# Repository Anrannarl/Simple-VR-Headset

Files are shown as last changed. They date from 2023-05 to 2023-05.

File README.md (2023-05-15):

# Simple-VR-Headset
A simple VR headset designed for HadesVR.  
https://github.com/HadesVR/HadesVR  
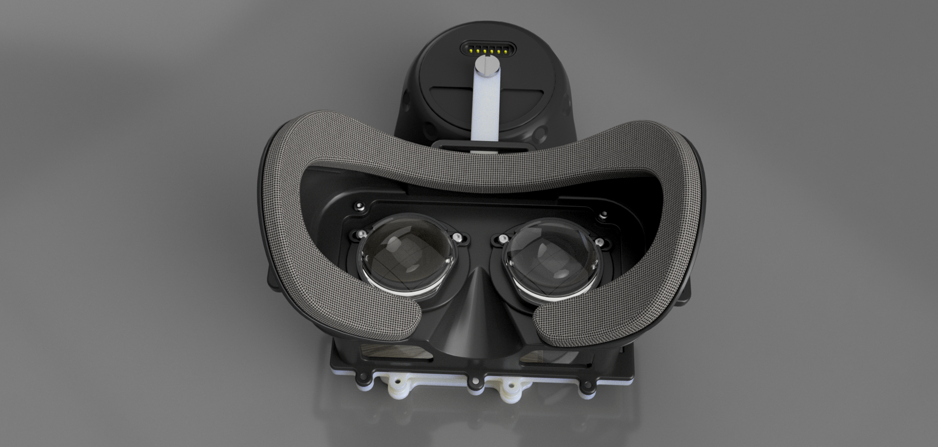
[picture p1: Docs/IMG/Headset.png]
  
  


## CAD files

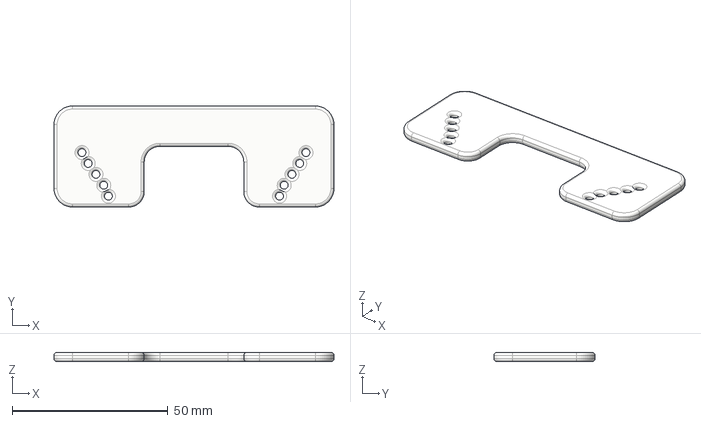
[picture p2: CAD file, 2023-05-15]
STEPs/IPD Tool.step
90.0 x 32.5 x 3.00 mm

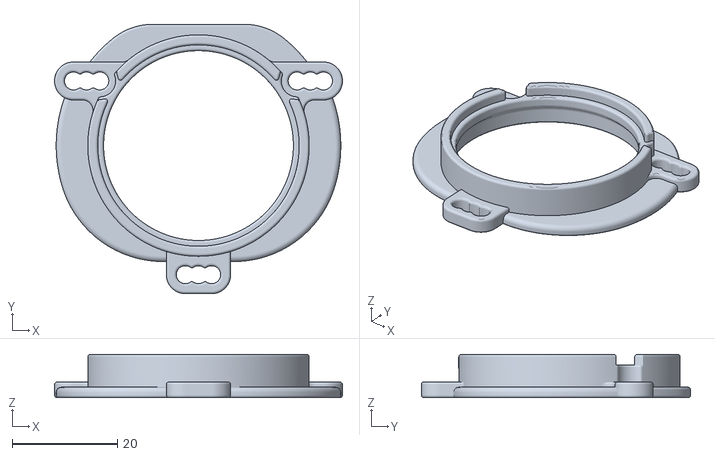
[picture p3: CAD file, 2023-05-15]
STLs/Lens Cup/GearVR White Lens Cup.stl
54.6 x 51.1 x 8.25

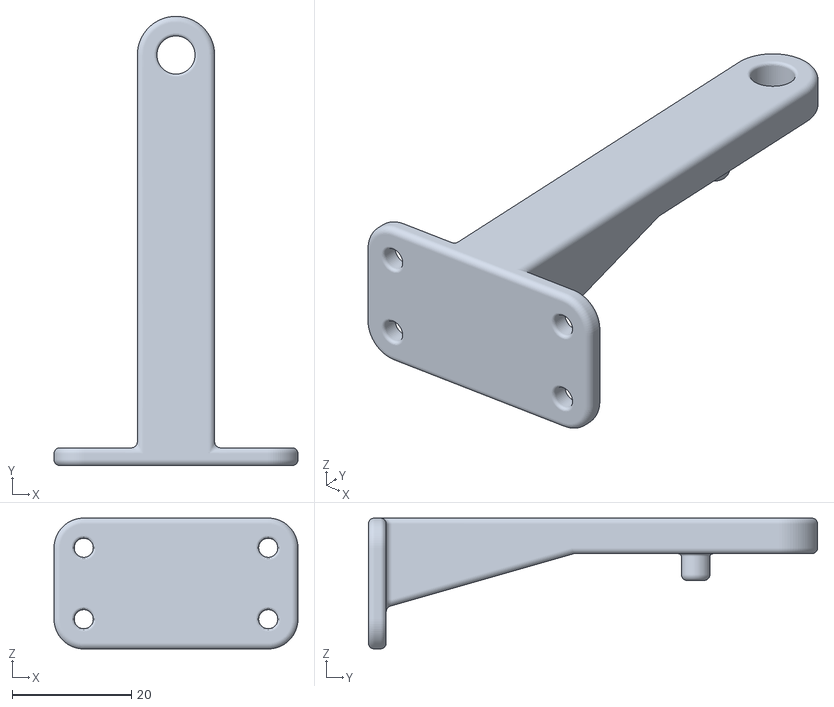
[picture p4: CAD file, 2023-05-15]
STLs/Tracker Mount.stl
41.0 x 75.5 x 22.0

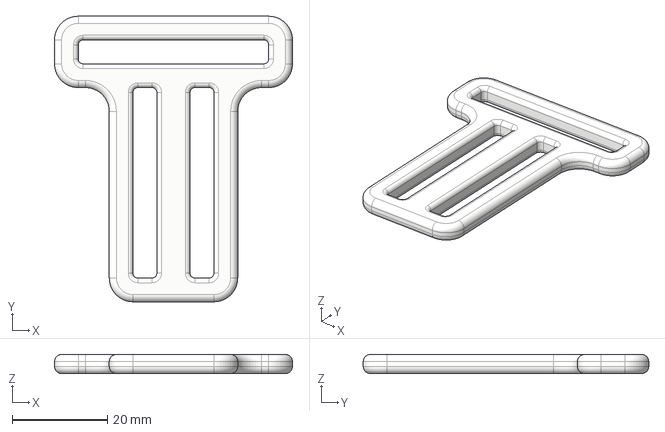
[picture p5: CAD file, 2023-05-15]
STEPs/Head Strap Hook.step
50.0 x 60.0 x 4.00 mm

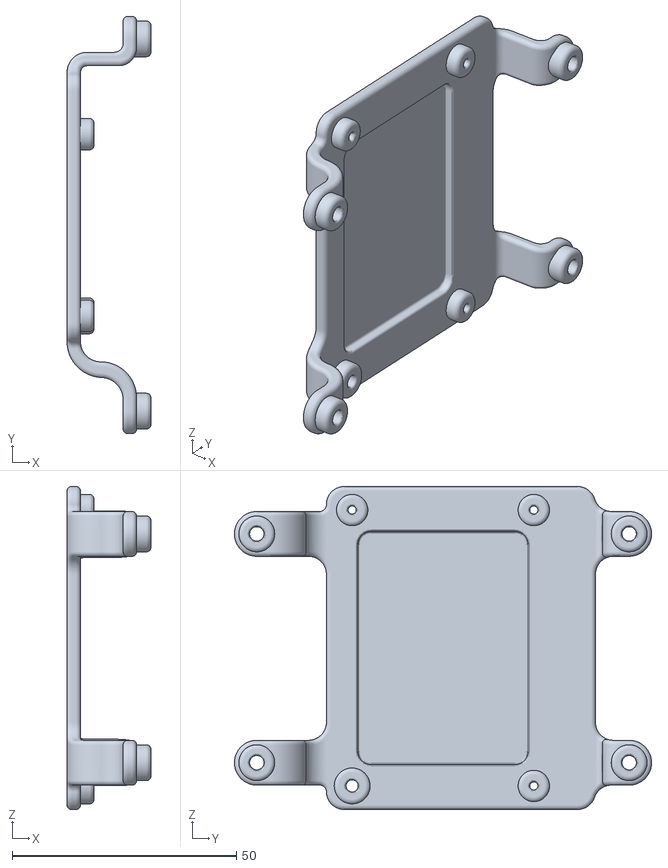
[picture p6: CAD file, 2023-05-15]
STLs/HDMI PCBA Mount.stl
18.7 x 93.0 x 72.0

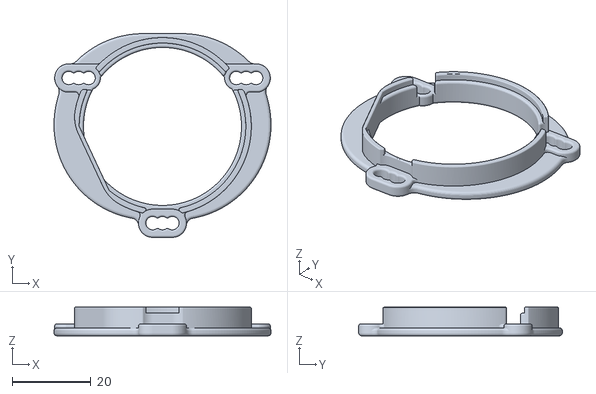
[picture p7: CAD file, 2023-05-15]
STLs/Lens Cup/GearVR Black Lens Cup Right.stl
55.0 x 51.6 x 7.25

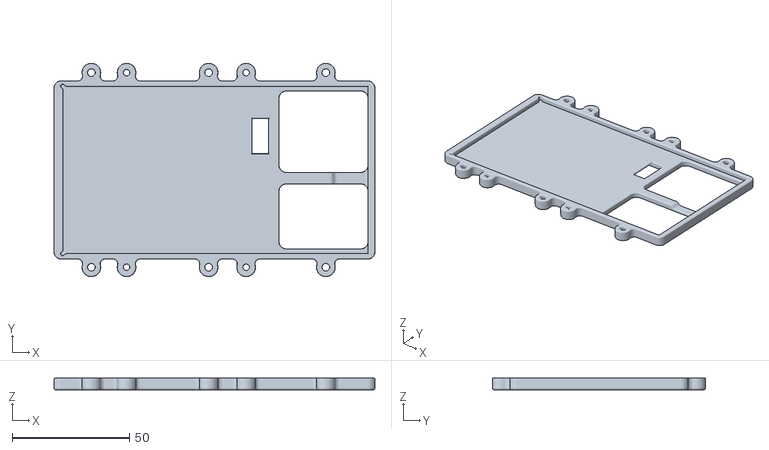
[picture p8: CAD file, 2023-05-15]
STLs/Screen Frame.stl
136.9 x 91.0 x 5.25

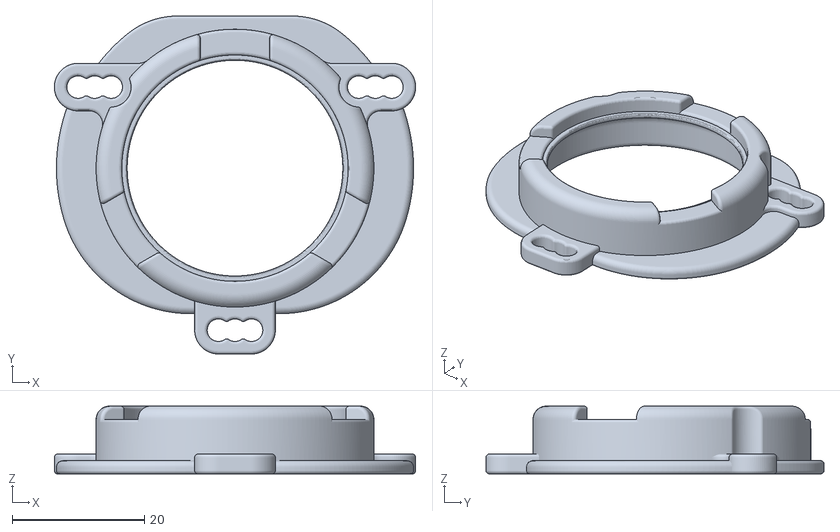
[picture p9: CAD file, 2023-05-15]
STLs/Lens Cup/Cardboard Lens Cup.stl
54.6 x 51.1 x 10.2

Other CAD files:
STLs/Lens Cup/GearVR Black Lens Cup Left.stl
STLs/Head Strap Hook.stl
STLs/IPD Tool.stl

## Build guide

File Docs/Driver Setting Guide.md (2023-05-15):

# Driver Setting Guide
For the general setup guide, please refer to HadesVR. https://github.com/HadesVR/HadesVR  
To use the Vive tracker for headset tracking, please refer to this link. https://github.com/Yersi88/WMR-and-Vive-Tracker  
The tracker position needs to be offset to the center position of your eyes.  
You can find the example tracker json files in the Vive Tracker JSON folder.  
Note that they are for reference only. You need to use json files extracted from your own Vive tracker.  

Setting profiles:  

GearVR Black  
"FOV" : 90,  
"ViewportZoom" : 0.79,  
"Red_K1" : 0.50,  
"Red_K2" : 2.4,  
"Green_K1" : 0.55,  
"Green_K2" : 2.4,  
"Blue_K1" : 0.7,  
"Blue_K2" : 2.4,  

GearVR White  
"FOV" : 90,  
"ViewportZoom" : 0.80,  
"Red_K1" : 0.70,  
"Red_K2" : 1.7,  
"Green_K1" : 0.75,  
"Green_K2" : 1.7,  
"Blue_K1" : 0.9,  
"Blue_K2" : 1.7,  

Google Cardboard V2  
"FOV" : 80,  
"ViewportZoom" : 0.87,  
"Red_K1" : 0.29,  
"Red_K2" : 0.56,  
"Green_K1" : 0.34,  
"Green_K2" : 0.56,  
"Blue_K1" : 0.48,  
"Blue_K2" : 0.56,  

"IPD" : 0.063,  
"DistanceBetweenLenses" : 0.063,  
"DistanceBetweenViews" : 0.063,  
"DisplayWidth" : 0.12096,  

"IPD" should be set to your real IPD  
"DistanceBetweenLenses" should be set to the physical distance between the two lens centers    
"DistanceBetweenViews" should be set to the same value as "DistanceBetweenLenses"  
"DisplayWidth" is the physical width of the display

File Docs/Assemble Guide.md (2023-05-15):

# Assemble Guide  
Components needed:  
For the display and driver board, please refer to HadesVR. https://github.com/HadesVR/HadesVR  
Print all files in the STLs folder. Choose the correct lens cup model for the lenses you plan to use.  
I recommend using the lenses from the GearVR headset(2017/black version).  
If the filament you have is not black, you need black paint to paint the interior of the headset black.  
Gather the following screws: 15 * M3x6, 6 * M3x8, 4 * M3x10,  3 * M2x6, 1 * 1/4''x10mm(Vive tracker)  
Additionally, you need a thin HTC Vive face pad, some velcro hooks(with adhesives), some velcro strap and double side tape.  
Steps:  
1. Pry the lenses off from the GearVR headset.  
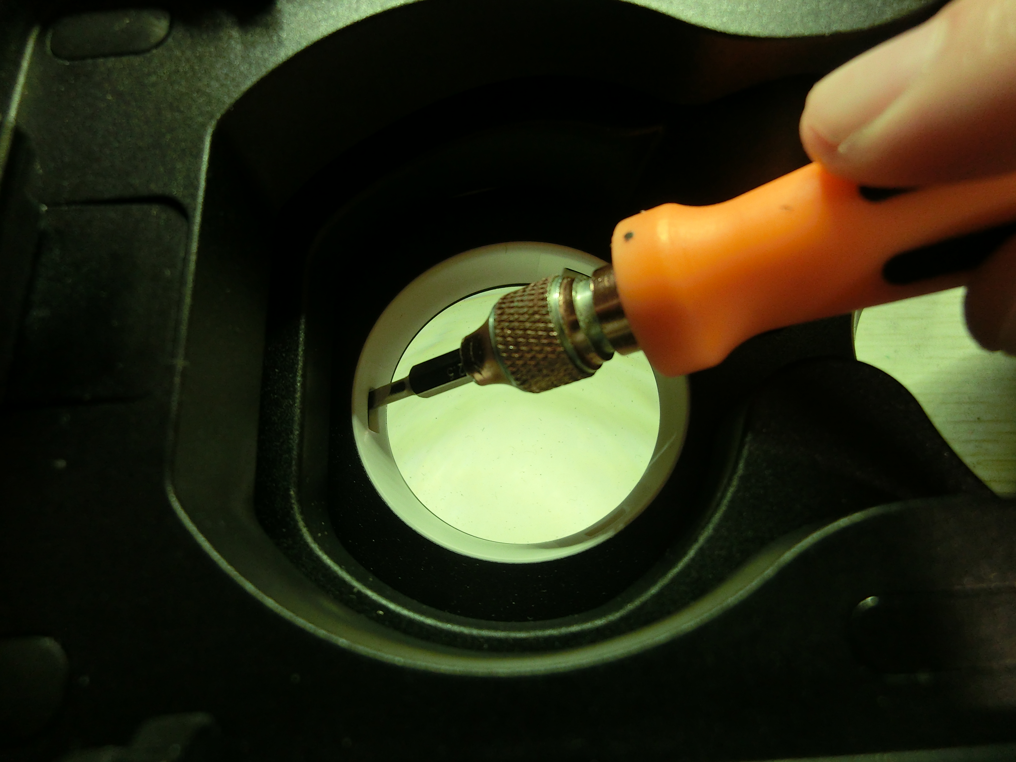
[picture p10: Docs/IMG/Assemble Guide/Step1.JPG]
  
2. Fix the adapter board to the screen frame with double side tape.
  
3. Fix the display to the screen frame with double side tape.  
  
4. Connect the ribbon cable to the adapter board.  
  
5. Fix the display driver board to the mount with screws.  
Screws: 3 * M2x6, 1 * M3x6  
  
6. Connect the ribbon cable from the adapter board to the display driver board.  
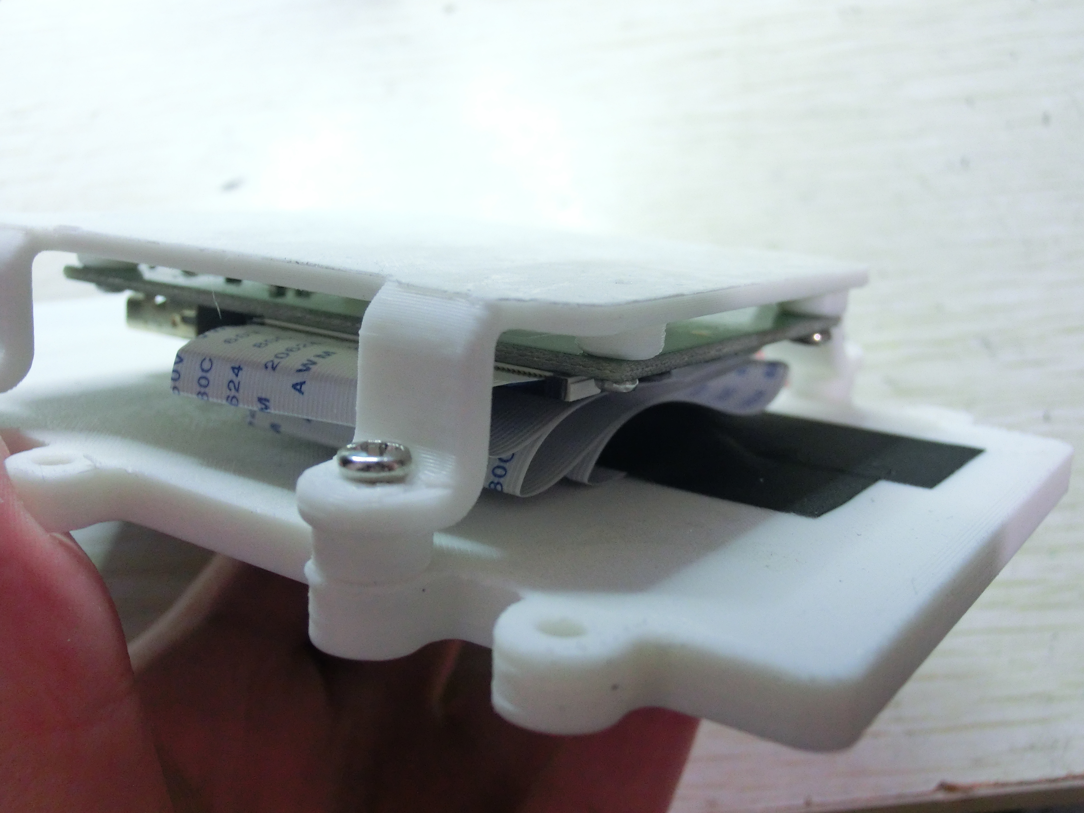
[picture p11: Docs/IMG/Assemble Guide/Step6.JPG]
  
7. Fix the mount to the screen frame with screws.  
Screws: 4 * M3x10  
  
8. Assemble the rest of the headset with screws.  
Screws: 8 * M3x6  
  
9. Put the lens cups to the correct positions to match your IPD.  
IPD settings: 58mm, 63mm, 68mm  
Screws: 6 * M3x6  
If you don't know your IPD, measure it with the IPD tool.
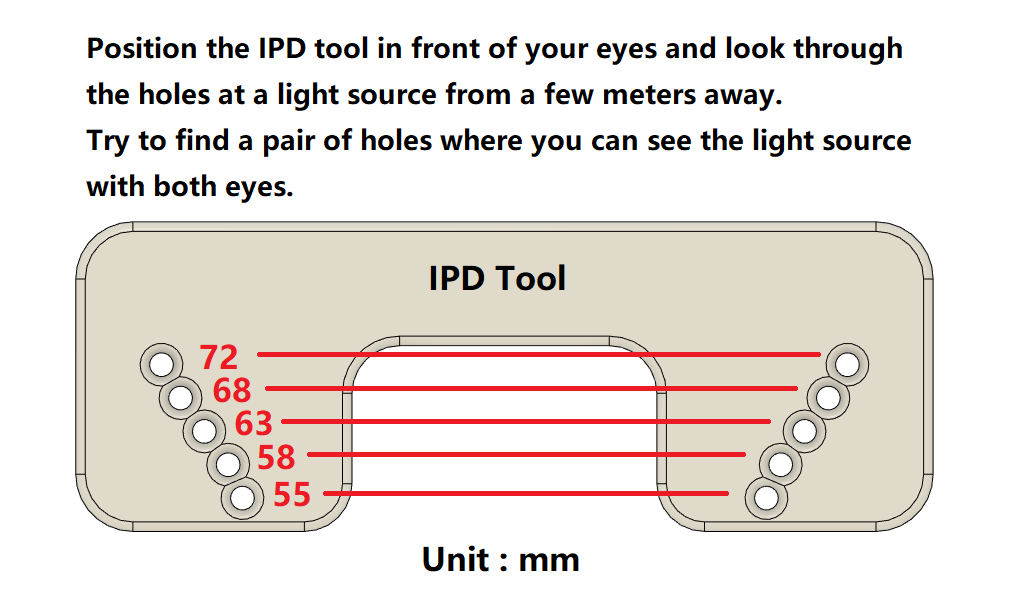
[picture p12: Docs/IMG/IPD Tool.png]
  
  
10. Put in the lenses and stick the velcro hooks to the facial interface. Then assemble the screen frame and lens box with screws.  
Screws: 6 * M3x8  
  
11. Put in the face pad and straps.  
  


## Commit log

2023-05-15 Update Assemble Guide.md
2023-05-15 Update and rename Setting Guide.md to Driver Setting Guide.md
